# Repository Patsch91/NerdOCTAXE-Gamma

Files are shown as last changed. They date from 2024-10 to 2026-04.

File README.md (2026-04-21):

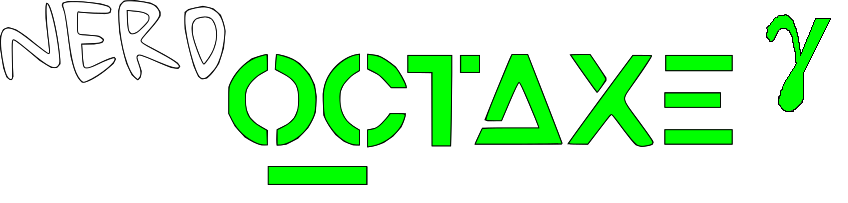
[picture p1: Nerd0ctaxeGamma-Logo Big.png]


**NerdOCTAXE-γ Rev3.4  **

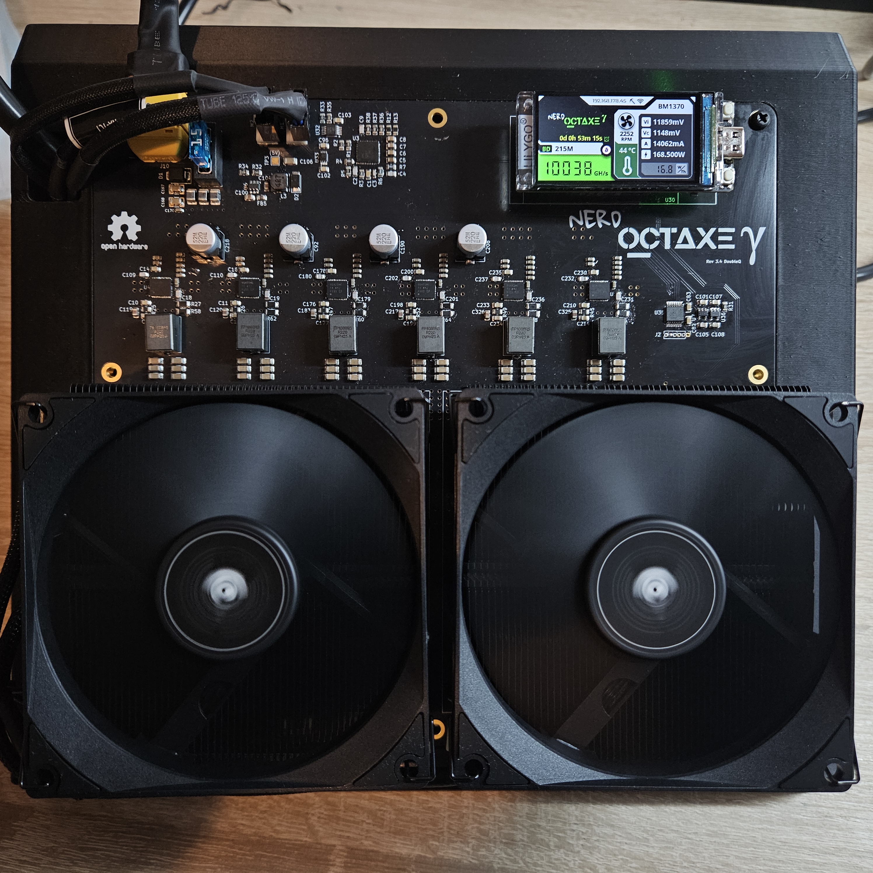
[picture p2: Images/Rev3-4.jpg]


Rev3.4:
- 6 Phase Buck Converter
- Added curcuit to read the internal temperature of each asic

The NerdOCTAXEγ runs with a modified version of the AxeOS: [ESP-Miner-NerdQAxe+](https://github.com/shufps/ESP-Miner-NerdQAxePlus) (Releases for NerdOCTAXE-Gamma)

To flash the Lilygo T-Display you can use the [Webflasher](https://shufps.github.io/nerdqaxe-web-flasher/)

-------------------------------

# Build

**DISCLAIMER:** This device is an *highly advanced* build and partly WIP. To get 8 Asics and the voltage regulator soldered properly *can* be very hard and frustrating if you are not used to soldering Asics or soldering in general. Using that amount of power, this device isn't a toy and you should know what you are doing - stay safe! Also this device is not intended or designed to run overclocked.

**PCB:** For example with the JLC Plugin for Kicad you can export the files out of Kicad to order directly from JLCPCB or any other PCB-Manufacturer. I tested my prototype with 1oz on inner and outer layers... working nice :) If anyone is testing 2/1oz or 2/2oz please let me know of the results you are seeing!

**BOM:** You can directly upload the .csv in this repo to Digikey. You will have to order the Lilygo T-Display S3 and the XT60PW-M seperately 

**HEATSINKS:** For this build I used two Thermalright AXP90-X53 

**ASICS:** This board utilizes Bitmains BM1370-Series. I tested boards with the following variants: BM1370BC < BM1370PA < BM1370PF 

Misc
====
If you like this project and want to support future work, feel free to donate to:
**`bc1q0ctaxeha3lpsaaz7kpjulflw2d9p66fhkp48dk`**

or related projects without which this project would not have been possible for me:

[Nerdaxe](https://github.com/BitMaker-hub/NerdAxeUltra)

[NerdQAxe+](https://github.com/shufps/qaxe)

[OSMU](https://osmu.wiki/)

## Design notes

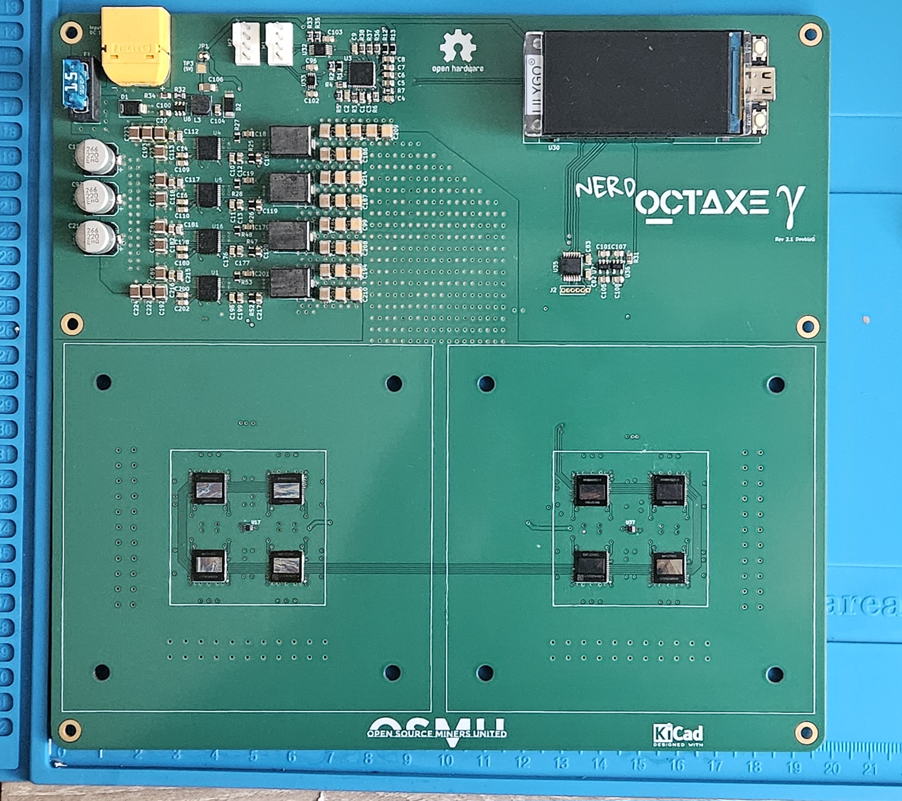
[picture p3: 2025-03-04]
Images/NerdOCTAXE-Gamma_DoubleQ PCB.jpg

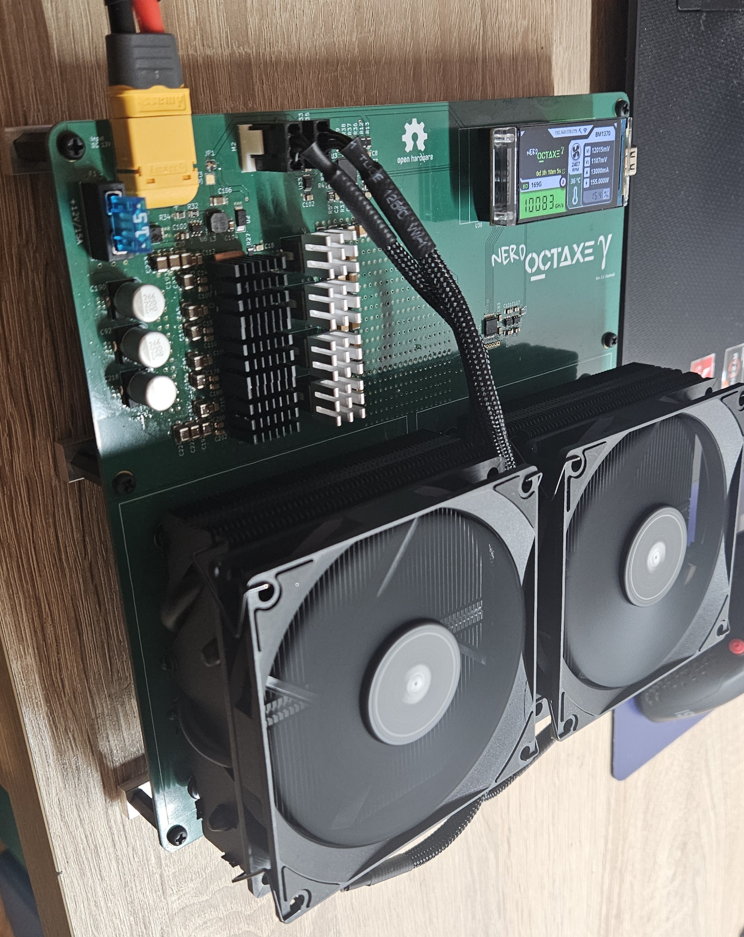
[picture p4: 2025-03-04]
Images/NerdOCTAXE-Gamma_DoubleQ (2).jpg

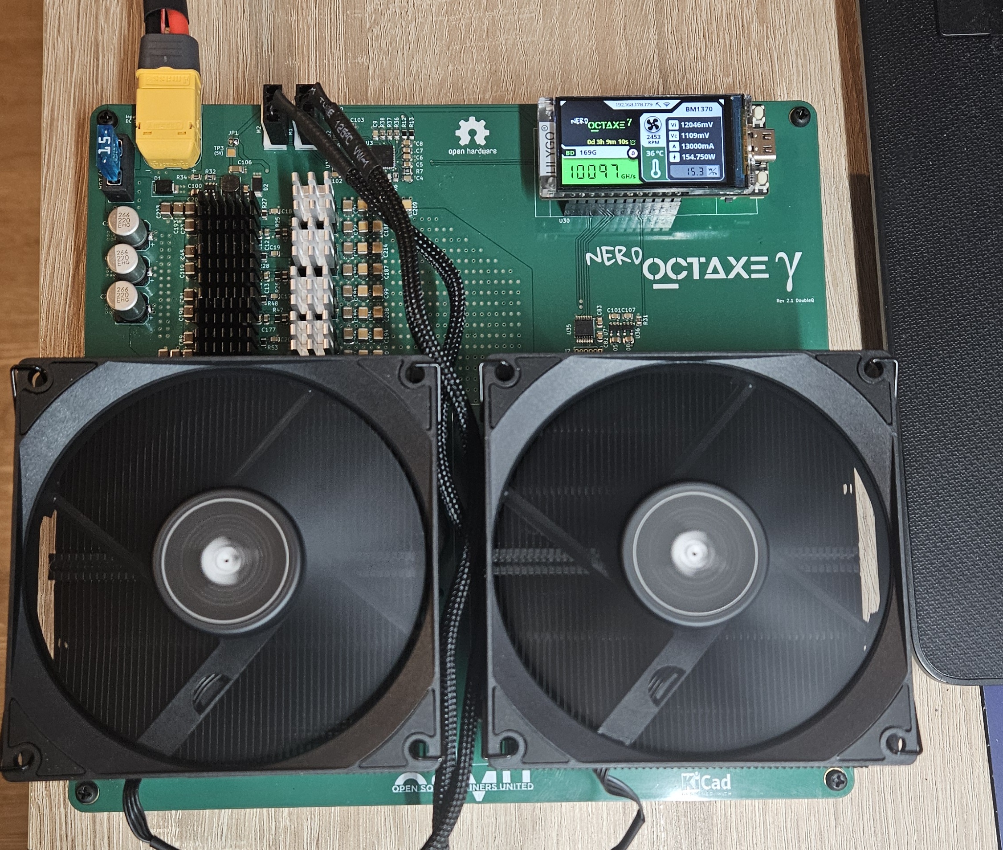
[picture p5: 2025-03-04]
Images/NerdOCTAXE-Gamma_DoubleQ.jpg

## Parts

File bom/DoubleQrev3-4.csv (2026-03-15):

Reference | Value | Footprint | Qty | Distributor | OrderNr
C1 | 2.2n | Capacitor_SMD:C_0805_2012Metric | 1 | D | 1276-2993-1-ND
C2,C4,C9,C109,C110,C180,C202,C212,C232,C237,C327 | 1n/0.7mm | Capacitor_SMD:C_0805_2012Metric | 11 | D | 490-6445-1-ND
C3 | 12p | Capacitor_SMD:C_0603_1608Metric | 1 | D | 478-KGM15ACG2A120JMCT-ND
C5 | 330n | Capacitor_SMD:C_0805_2012Metric | 1 | D | 399-C0805C334K3RECAUTOCT-ND
C6,C8,C15,C17,C26,C27,C28,C30,C33,C35,C36,C37,C38,C40,C41,C42,C43,C44,C46,C49,C52,C54,C55,C56,C57,C58,C59,C60,C61,C62,C63,C65,C68,C70,C71,C72,C73,C74,C75,C76,C77,C78,C79,C85,C105,C108,C121,C123,C124,C125,C126,C127,C128,C129,C130,C131,C132,C134,C137,C139,C140,C141,C142,C143,C144,C145,C146,C147,C148,C150,C153,C155,C156,C157,C158,C159,C160,C161,C162,C163,C164,C166,C169,C171,C172,C173,C174,C175,C195,C196,C197,C203,C204,C211,C219,C221,C225,C226,C227,C228 | 1µ/25V | Capacitor_SMD:C_0805_2012Metric | 100 | D | 1276-1066-1-ND
C7 | 4.7µ | Capacitor_SMD:C_0805_2012Metric | 1 | D | 1276-1244-1-ND
C10,C11,C14,C16,C25,C82,C83,C87,C88,C96,C101,C102,C103,C107,C176,C178,C198,C200,C210,C229,C230,C233,C235 | 100n/0.7mm | Capacitor_SMD:C_0805_2012Metric | 23 | D | 311-3037-1-ND
C12,C13,C177,C199,C214,C234 | 2.2µ | Capacitor_SMD:C_0805_2012Metric | 6 | D | 1276-6458-1-ND
C18,C19,C179,C201,C231,C236 | 6.8n | Capacitor_SMD:C_0805_2012Metric | 6 | D | 490-GRM2165C2A682JA01DCT-ND
C20,C23,C29,C34,C45,C47,C53,C64,C69,C80,C81,C89,C111,C112,C113,C117,C118,C122,C133,C135,C136,C138,C149,C151,C152,C154,C165,C170,C181,C182,C191,C192,C207,C209,C215,C216,C222,C296,C297,C298,C299,C300,C301,C302,C303,C304,C305,C306,C307,C308,C309,C310,C311,C312,C313,C314,C315,C316,C317,C318,C319,C320,C321,C322,C323,C324 | 10uF | Capacitor_SMD:C_0603_1608Metric | 66 | D | 1276-1870-1-ND
C21,C22,C24,C31,C32,C39,C48,C50,C51,C66,C67,C84,C86,C90,C91,C93,C94,C95,C97,C98,C99,C184,C185,C186,C187,C188,C189,C193,C194,C206,C223,C224,C238,C239,C240,C241,C242,C243,C244,C245,C246,C247,C248,C249,C250,C251,C252,C253,C254,C255,C256,C257,C258,C259,C260,C261,C262,C263,C264,C265,C266,C267,C268,C269,C270,C271,C272,C273,C274,C275,C276,C277,C278,C279,C280,C281,C282,C283,C284,C285,C286,C287,C288,C289,C290,C291,C292,C293,C294,C295,C480,C481 | 100µF | Capacitor_SMD:C_1206_3216Metric | 92 | D | 1276-1782-1-ND
C92,C190,C208,C218,C329 | 220µ/25V | Capacitor_SMD:CP_Elec_8x10 | 5 | D | 565-HHXE250ARA221MHA0GCT-ND
C100,C119,C120,C183,C217,C325,C326 | 10µ | Capacitor_SMD:C_0805_2012Metric | 7 | D | 445-5984-1-ND
C104 | 10n | Capacitor_SMD:C_0805_2012Metric | 1 | D | 445-6947-1-ND
C106 | 22µ/16V | Capacitor_SMD:C_1206_3216Metric | 1 | D | 1276-2728-1-ND
C114,C115,C116 | 22p | Capacitor_SMD:C_0603_1608Metric | 3 | D | 478-KGM15ACG1H220JTCT-ND
C167,C168 | 10µ | Capacitor_SMD:C_1210_3225Metric_Pad1.33x2.70mm_HandSolder | 2 | D | 1276-6767-1-ND
C205,C213,C220,C328 | 100nF | Capacitor_SMD:C_0805_2012Metric | 4 | D | 399-C0805C104K5RACTUCT-ND
D1 | SMBJ12A | Diode_SMD:D_SMB | 1 | D | SMBJ12ALFCT-ND
D2 | PMEG4030EP,115 | Diode_SMD:D_SOD-128 | 1 | D | 1727-5841-1-ND
D3 | 1N5819 | Diode_SMD:D_SOD-123 | 1 | D | 31-1N5819HWQ-7-FCT-ND
F1 | 3568 | 8Axe:Fuseholder Blade_3568 | 1 | D | 36-3568-ND
FB1,FB2,FB3,FB4,FB5 | BLM21PG221SN1D | Resistor_SMD:R_0805_2012Metric | 5 | D | 490-1054-1-ND
FB6,FB7,FB8 | BLE32SN120SN1L | Resistor_SMD:R_1210_3225Metric_Pad1.30x2.65mm_HandSolder | 3 | D | 490-BLE32SN120SN1LCT-ND
J5,J6 | Conn_01x12-Socket |  | 2 | D | 732-61301211821-ND
J7,J8 | Conn_01x12-Header |  | 2 | D | 2057-PH1-12-UA-ND
J10 | Connector 02x01 | Connector_AMASS:AMASS_XT60PW-M_1x02_P7.20mm_Horizontal | 1 | X
L1,L2,L4,L5,L6,L7 | 220nH | Nerd8:IFLR-4031GC-01-8x10 | 6 | D | 283-FP1008R5-R220-RCT-ND
L3 | 4.7µH/2.3A/2.7A | Inductor_SMD:L_Taiyo-Yuden_NR-50xx | 1 | D | 732-7244-1-ND
M1,M2 | Fan_4pin | Connector:FanPinHeader_1x04_P2.54mm_Vertical | 2 | D | WM4330-ND
R1 | 16.5k | Resistor_SMD:R_0805_2012Metric | 1 | D | 541-16.5KCCT-ND
R2 | 24.3k | Resistor_SMD:R_0805_2012Metric | 1 | D | 311-24.3KCRCT-ND
R3 | 24.9k | Resistor_SMD:R_0805_2012Metric | 1 | D | RMCF0805FT24K9CT-ND
R4 | 100k | Resistor_SMD:R_0805_2012Metric | 1 | D | RMCF0805FT100KCT-ND
R5 | 121k | Resistor_SMD:R_0805_2012Metric | 1 | D | RMCF0805FT121KCT-ND
R6 | 8.06k | Resistor_SMD:R_0805_2012Metric | 1 | D | RMCF0805FT8K06CT-ND
R7 | 2.55k | Resistor_SMD:R_0805_2012Metric | 1 | D | 311-2.55KCRCT-ND
R8,R10,R14,R16,R18,R20,R22,R24,R31,R36,R37,R38,R42,R57 | 10k | Resistor_SMD:R_0805_2012Metric | 14 | D | RMCF0805FT10K0CT-ND
R9,R11,R15,R17,R19,R21,R23,R41 | 1k | Resistor_SMD:R_0805_2012Metric | 8 | D | RNCP0805FTD1K00CT-ND
R12,R13 | 2.2R/0.5W | Resistor_SMD:R_0805_2012Metric | 2 | D | 541-10524-1-ND
R25,R26,R45,R47,R49,R52 | 1R/0.5W | Resistor_SMD:R_0805_2012Metric | 6 | D | 541-1.00TCT-ND
R27,R58,R59,R60,R61,R62,R63,R64,R65,R66,R67,R68 | 2R/1W | Resistor_SMD:R_1206_3216Metric | 12 | D | 541-10616-1-ND
R29,R30 | 0 | Resistor_SMD:R_0805_2012Metric | 2 | D | RMCF0805ZT0R00CT-ND
R32 | 84.5k | Resistor_SMD:R_0805_2012Metric | 1 | D | 311-84.5KCRCT-ND
R33,R35,R43,R44 | 2.7k | Resistor_SMD:R_0805_2012Metric | 4 | D | RMCF0805FT2K70CT-ND
R34 | 16.2k | Resistor_SMD:R_0805_2012Metric | 1 | D | RMCF0805FT16K2CT-ND
R39,R40,R51,R54,R55,R56 | 100 | Resistor_SMD:R_0805_2012Metric | 6 | D | 311-100CRCT-ND
U1,U4,U5,U16,U18,U19 | CSD95472Q5MC | Nerd8:CSD95472-SON-5x6 | 6 | D | 296-43950-1-ND
U2,U9,U10,U11,U12,U13,U14,U15 | BM1370_mode1 | Nerd8:BM1370 | 8 | X
U3 | TPS53667 | Package_DFN_QFN:Texas_RHA0040B_VQFN-40-1EP_6x6mm_P0.5mm_EP4.15x4.15mm_ThermalVias | 1 | D | 296-44940-1-ND
U6 | AP3211 | Package_TO_SOT_SMD:SOT-23-6 | 1 | D | AP3211KTR-G1DICT-ND
U7 | MCP1824T-0802E | Package_TO_SOT_SMD:SOT-23-5 | 1 | D | MCP1824T-0802E/OTCT-ND
U8 | 25MHz | Oscillator:Oscillator_SMD_EuroQuartz_XO32-4Pin_3.2x2.5mm | 1 | D | 1923-1664-1-ND
U17,U37,U38 | TMP1075 | Nerd8:TMP1075-DRL | 3 | D | 296-TMP1075NDRLRCT-ND
U20 | TMP451A | Package_SON:WSON-8-1EP_2x2mm_P0.5mm_EP0.9x1.6mm | 1 | D | 296-TMP451AQDQWRQ1CT-ND
U21,U23 | TMUX1109RSVR | Package_DFN_QFN:UQFN-16_1.8x2.6mm_P0.4mm | 2 | D | 296-53439-1-ND
U22 | TMP451J | Package_SON:WSON-8-1EP_2x2mm_P0.5mm_EP0.9x1.6mm | 1 | D | 296-TMP451JQDQWRQ1CT-ND
U30 | T-Display-S3 | myfootprints:T-Display-S3 | 1 | X
U32 | EMC2302-1 | Package_SO:MSOP-10_3x3mm_P0.5mm | 1 | D | EMC2302-1-AIZL-CT-ND
U33 | TXU0102-DCU | Package_SO:VSSOP-8_2.3x2mm_P0.5mm | 1 | D | 296-TXU0102DCURCT-ND
U35 | TXU0304PW | Package_SO:TSSOP-14-1EP_4.4x5mm_P0.65mm | 1 | D | 296-TXU0304PWRCT-ND
U36 | MCP1824T-1202E | Package_TO_SOT_SMD:SOT-23-5 | 1 | D | MCP1824T-1202E/OTCT-ND

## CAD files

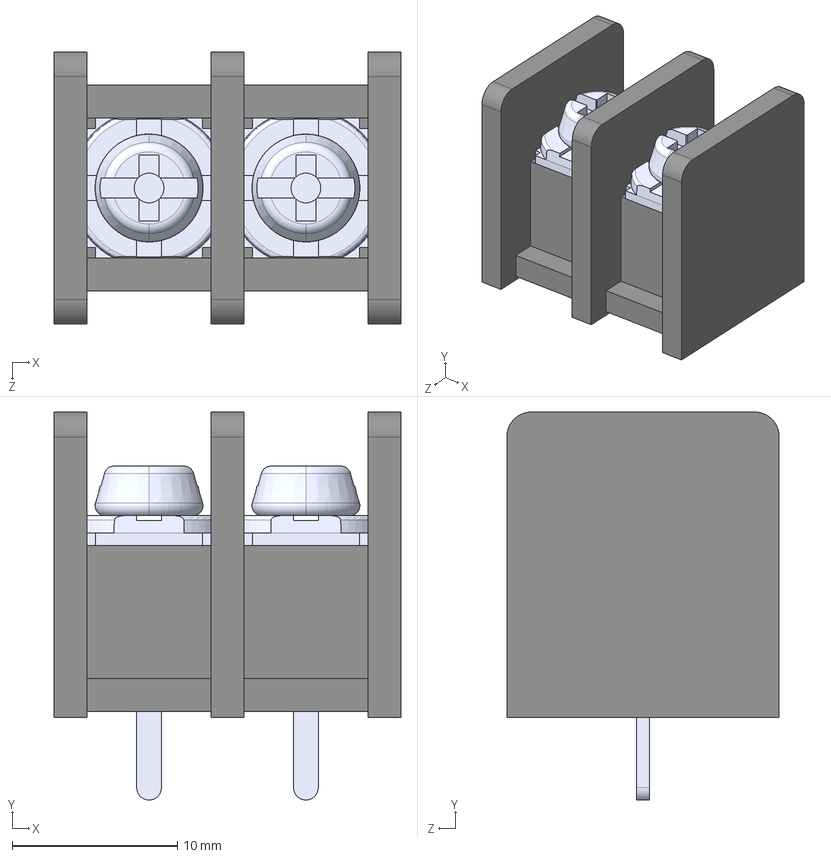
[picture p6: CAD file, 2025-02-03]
3d/OSTYK51102030.STEP
21.0 x 23.5 x 16.5 mm

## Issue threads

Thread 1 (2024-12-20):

Contact

minimalist15, 2024-12-20:
Hi,
first of all amazing stuff you're doing..
I wanted to try and build one as well but I am a bit confused as to what is your "final" set up for the moment in terms of BOM.
I saw you suggested to use different heatsinks and that you have moved to a 6 layer PCB.
I would like to try to do this as well, just curious as to what guidelines you'd give now as some time has passed since your last updates.
Wanted to reach out but couldn't find you anywhere.

Patsch91, 2024-12-27:
Hi,
I would recommend to use the "LED" branch with at least 1/1oz on the PCB. This PCB is running for weeks now without any major problems :)
In the LED-branch you will find the heatsinks I recommend to use... I did ot find any better alteratives regarding price and size as the space is limited by the case :)
If you have anyy specific questions, just let me know!

Closed 2025-03-30.

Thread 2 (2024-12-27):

cooler compatibility

DerpMcGeee, 2024-12-27:
can you change the holes into slots to be compatible with am4 coolers? 90x54 compared to the 94x56

DerpMcGeee, 2024-12-27:
too small to cover asics ignore me

ixtech-designs, 2025-03-28:
the LGA_Design branch has footprint to match the LGA115X coolers

Closed 2025-03-30.

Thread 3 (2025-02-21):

Guide

AlvaTM, 2025-02-21:
I'm really intrested in this project but I have the worst time understanding github and how things are in steps on here. Do you by chance have a the guide on another site? If not I understand. But this project is really cool!

Patsch91, 2025-04-02:
Hi, where excactly do you need some guidance?  In general terms you can open up the Boardfile with KiCad and download for example the Fabrication-Toolkit Plugin. This will export you the gerber files. You can upload these to a PCB manufacturer and let produce it. The parts needed you can find inn the "BOM"-folder.  With the PCB and the Parts at your hand you can open up the "ibom.html" and start soldering it all together :)  I wouldn´t recommend to start with this project without some (many) hours of soldering experience! Probably would get frustrating very fast :)

luiskellermann, 2025-05-07:
Hi Patsch91, i also wanna solder your project myself. Could you contact me on telegram for a quick guidance on how to order on JLCPCB. I just wanna make sure that I clicked the right boxes on KICAD for the export of the Gerber files and for the purchasing on JLCPCB. Would be very kind if you can dm me on telegram. Telegram Username: @luiskellermann

luiskellermann, 2025-05-07:
And can you clarify which of the 3 BOM's is the right one. I wanna order the best working built you currently have. Thank you so much.

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

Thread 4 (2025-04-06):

Regulator very hot, probably assembly defect...

earlynerd, 2025-04-06:
Hi, I built a small run of your octaxe lga design! First I want to say thanks for publishing such a professional hardware design, having it fabricated and purchasing components was easy. I am fairly experienced in smt assembly, and have stuffed the boards by hand with a solder stencil.

It looks great, it boots up, the log says that it finds all 8 Asics, it ramps up their clocks and connects to my pool, and then... The regulator chips get screaming hot, over 100C, over a few seconds and the power cycles on and off. Alternating between like 225W and 0W.  It never reports any hashes.

I expect I've probably made an error in assembly for these boards. This is the first miner I've ever built. Or used actually. I measure like 1.9 Ohms across the Asic power pads of the bare chips. My first thought was a short circuit on the 1V rail but I can't seem to find it.

I wanted to ask if you had any thoughts about what my issue might be. I've pulled the Asics off of it and the short circuit is gone, but maybe the low resistance I was measuring is normal?

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

Patsch91, 2025-04-06:
Hey there! First you definately want to put any kind of heatsinks on the 4 Mosfets to get them cooler. I can´t run the Octaxe without heatsinks on the 4xCSDs - thats why I am constantly trying to improve the Buck Section for better cooling options at the moment :)

The low resistance between the big asic pads is normal.
My guess would be that the Buck went to overtemperature fault mode and shut off. So first I would try to put the best kind of heatsink option you could find and place them over the CSDs and try again. For first startups I recommend a Labbench PSU (capable of at least 15Amps at 12V) where you can observe the power drawn of the Miner to double check if the power values are correct in the OS. Another thing is to triple check if the heatsinks are mounted correctly (not bending the pcb but firm enough to make good contact - thats a veeeeeery thin line to walk on)

I once had an issue with alternating Wattage displayed on the OS ... After searching a lot it came out the TPS was a faulty one :/

Sooo in short words:
First check proper heatsink mounting and try to cool the 4xCSDs on the PCB in the best way you can do and try again with a PSU where you can check the power drawn of the PCB.
If the PSU shows consistently about 12-15Amps without jumping around - but the OS Wattage display is jumping around then probably check your tps!

Hope this helps!

earlynerd, 2025-04-06:
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

Thanks for the quick reply, I will try your suggestions! Thank you. These things getting scary hot

earlynerd, 2025-04-16:
So I have done some further investigating, stuffed several more boards, and still not really sure what's going on with my board.  I wanted to ask if you might share some kinda normal looking numbers for Pin, Pout, Iout, and temperature as reported from the TPS on one of your boaeds? Mine are quite bad, and I am still hunting for the reason why. Even dropping the voltage and Asic frequency very low using the config and sticking a heatsink on I can't get it to run for more than a minute. Efficiency according to Pout/Pin is around 50% and I know that this type of regulator commonly is above 90%. I have a bench supply at work that can provide 20A and the number it reported seemed to match what was shown on the display.

I added some code to dump the TPS registers and did not find anything more interesting than the fact that it increases in temperature until it hits 125C and then shuts off.  The config it is reporting at runtime matches what it's being initialized with.  It isn't reporting any other faults. On boards without Asics installed it runs fine, but theres no load in that case...

Patsch91, 2025-04-16:
Ok that sounds a bit weird ... could you send me a picture of the heatsinks you are using on the CSDs?
What is the layer thickness of your PCB?
How many Watts is your UI and the PSU showing until it shuts off?

earlynerd, 2025-04-16:
I sliced a few fins off a larger heatsink. I've been looking for one that fits the mounting pattern on your board without a lot of luck, I may machine something better. I've also been sticking a heatsink to the bottom under the regulator since the csds will reject a lot of their heat into the board itself. I can't keep them from overheating even when pointing an electric duster at the heatsink.

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

I also added a dummy load to a different board that is fully populated except for the Asics. A few feet of 18awg wire. The logs say that it consumed 47W from the 12V supply to put 25W into the load.

I ordered the pcbs from JLC and selected 1oz outer and 1oz inner copper, so there's 6oz total thickness there.

Here's a Serial log output of it booting up and then overheating. It doesn't actually get all the way through the frequency ramp up.

[nerdaxe boot apr11.txt](https://github.com/user-attachments/files/19772275/nerdaxe.boot.apr11.txt)

Here's a thermal cam video of turning it on. Heatsink removed here.
https://github.com/user-attachments/assets/bd13d03d-15d8-473a-95d1-1bd69ccb79b8

Probably next I will poke around with the oscilloscope.

Patsch91, 2025-04-20:
Oh well this definately isnt looking good! So there probably is a solder issue :/

I have a 1/1oz Board too, so this wont be the problem ... I only can think of a soldering issue on the CSDs.

Ah well and I see on the Picture you send (Backside with the heatsink) it looks like somethin is wrong with your C116!

earlynerd, 2025-04-20:
I just discovered that damaged capacitor (and pad) and the resistor next to it was damaged also, good eye spotting that in the photo.

I've now got two more units that are hashing on one Asic each successfully. I think the issue was indeed mostly solder related. I do still measure lower than ideal efficiency on the boards which are hashing, but it may be due to the load being too light with only one asic. And I also measure that the displayed input current is not correct, off by almost 20%.  so any efficiency calculated based on that will not be useful anyway.

I think that the chip doesn't really have a direct measurement of input current and I guess it must calculate it from the phase current and the duty cycle. There's a register for calibrating the output current measurement offset which may improve the accuracy of the measurements it is making.

I will close this issue, thanks for your help.

Closed 2025-04-20.

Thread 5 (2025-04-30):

I2c pullups absent

earlynerd, 2025-04-30:
Doesn't appear that the i2c bus has any pullup resistors on SDA or SCL.  Internal pullups are not strong enough for i2c comms at 400khz (or even 100khz). The internal ones are ~45-50k but 400khz i2c requires 2.2k or so on both SDA and SCL.

Patsch91, 2025-04-30:
The displaymodule has internal pullups on GPIO43 and 44. I actually cann´t find any specific values but never had any problems on any board so far(Qaxe/Haxe/Octaxe etc)... Is there something not working on your board?

earlynerd, 2025-04-30:
There are no pullups on the display board. It somehow is working with only the internal pullups, but that can't be working very well or completely consistently. i can collect a scope shot to see if it is an issue, but you may consider adding the pullups to the latest revision anyway.

https://github.com/Xinyuan-LilyGO/T-Display-S3/blob/main/schematic/T_Display_S3.pdf

Patsch91, 2025-04-30:
Oh a scope shot would be very interesting then! Would love to see that!

earlynerd, 2025-04-30:
You can find the value of the internal pullups on the esp32-s3 datasheet page 29,
They are 45k. https://www.espressif.com/sites/default/files/documentation/esp32-s3-wroom-1_wroom-1u_datasheet_en.pdf

earlynerd, 2025-04-30:
Heres the scope shot. you can see how the clock signal never is able to return to high level while the transfer is happening. this is due to there not being stronger pullups to supply the current required to charge the bus capacitance. On the data line, it takes multiple bit periods before it returns to 90% of the supply voltage. Its impressive it still works, but its working in spite of the lack of pullups, and you should add the appropriate pullups for the speed of the bus to help make sure it always works.  I can Share the capture file if youd like to look closer. It can be opened in Saleae logic.

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

earlynerd, 2025-04-30:
I have fixed it already on my board, I undid the fix to capture this shot. I will put the pullups back and capture again for comparison

earlynerd, 2025-04-30:
This is with 2.2k pullup on SDA and SCL. 2.2k is not always the right value, it depends on the bitrate configured. It looks like it's being set up for 400khz in the firmware and 2.2k is a good value at 3.3V and that bitrate for most implementations.

Patsch91, 2025-04-30:
2,7k would already be in the Bom and would require additional part ... maybe that 2.7k would work good enough? :)

earlynerd, 2025-05-02:
Also I finally found the problem with the boards I built, I stuffed the regulator bootstrap caps with 1nF instead of 100nF 😬

Patsch91, 2025-05-05:
Added 2.7k resistors on SCL/SDA

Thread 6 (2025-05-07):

Question about ordering

luiskellermann, 2025-05-07:
Hi Patsch91, i also wanna solder your project myself. Could you contact me on telegram for a quick guidance on how to order on JLCPCB. I just wanna make sure that I clicked the right boxes on KICAD for the export of the Gerber files and for the purchasing on JLCPCB. Would be very kind if you can dm me on telegram. Telegram Username: @luiskellermann

luiskellermann, 2025-05-07:
And can you clarify which of the 3 BOM's is the right one. I wanna order the best working built you currently have. Thank you so much.

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

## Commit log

2024-08-20 Added 4th Phase Buck
    Started to add 4th Phase for the Buck, implementing BM1370 footprint etc
    [BM1368-1.kicad_sch, BM1368-2.kicad_sch, BM1368-3.kicad_sch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]
2024-08-25 Phase4 Disable
    Phase4-Disable Jumper
    [power.kicad_sch]
2024-08-25 Changed LDO to 1V2 and original 1V2 to VDD
    1V8 LDO replaced with 1V2 LDO
    Crystal replaced
    [BM1368-1.kicad_sch, BM1368-2.kicad_sch, BM1368-3.kicad_sch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]
2024-09-04 silkscreen changes
    heatsink area
2024-09-09 minor chages
    R3 to 49.9K
    added DK-Bom
    [bom.csv, designators.csv, octaxe-gamma.csv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]
2024-09-15 Changed to 6L PCB
2024-09-15 JLC
    JLC Zip File
    [bom.csv]
2024-10-27 Fuse from 12A to 15A
    [Nerd8.kicad_sch]
2024-10-29 changed imon to 33,2k for 180Amps
    [power.kicad_sch]
2024-10-29 update bom with 33.2k
    [octaxe-gamma_DigiKey.csv]
2024-11-03 Update README.md
    Case BOM
2024-11-03 Added 3D Files
    Backplate 3D Files
    [Backplate Octaxe.3mf, Backplate Octaxe.f3d, Backplate Octaxe.stl]
2024-11-07 LED Connector
    [Nerd8.kicad_pcb, pi.kicad_sch]
2024-11-07 100nF for TXU0101
    [Nerd8.kicad_pcb, pi.kicad_sch]
2024-11-07 Test bottomside open mask
    [Nerd8.kicad_pcb]
2024-11-10 layer switches
    [Nerd8.kicad_pcb]
2024-11-15 Input Cap 12V LED
    [Nerd8.kicad_pcb, Nerd8.kicad_sch, pi.kicad_sch]
2024-11-15 BOM changes
    1nF to 1nF 0.7mm etc
    [BM1368-1.kicad_sch, BM1368-2.kicad_sch, BM1368-3.kicad_sch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]
2024-11-15 BOM partdescriptions
    [BM1368-1.kicad_sch, BM1368-2.kicad_sch, BM1368-3.kicad_sch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]
2024-11-15 minor changes
    [Nerd8.kicad_pcb, bom.csv, designators.csv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]
2024-12-22 Added Backplate designs
    [Backplate logo with switch.3mf, Backplate logo with switch.stl, Backplate with logo.3mf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]
2025-02-06 GND Vias
    [Nerd8.kicad_pcb]
2025-02-07 XT60 test
    [Nerd8.kicad_pcb]
2025-02-07 12V Vias
    [Nerd8.kicad_pcb]
2025-03-04 mounting holes
    [Nerd8.kicad_pcb]
2025-03-14 Mountingholes CSD
    [Nerd8.kicad_pcb]
2025-03-15 0.16mm spacing
    [Nerd8.kicad_pcb]
2025-03-23 Buck rotation test
    Different Buck Layout
    [Nerd8.kicad_pcb, pi.kicad_sch, power.kicad_sch]
2025-05-05 added i2c pullups
    [Nerd8.kicad_pcb, pi.kicad_sch]
2025-05-05 Added pullups to bom and ibom
    [NerdOctaxe-Gamma DoubleQ_Digi.csv]
2025-09-30 board rev 3.0
    - 6 phases using TPS53667
    - Changed current MLCC capacitors to reduce BOM parts and rds on VRs
    - Beads at LDOs, TDisplay, fans and Power input (EMC)
    - Changed routing to allow better VDD circuit on bottom
    - Reduced VDD area to avoid EMI
    - New Layer distribution to reduce EMI
    [Asic0.kicad_sch, Nerd8.kicad_pcb, Nerd8.kicad_sch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]
2025-09-30 ibom update + bitronics logo
    [Nerd8.kicad_pcb]
2025-09-30 add gerbers + production files
    [CPL_file.csv, Nerd8-B_Cu.gbl, Nerd8-B_Mask.gbs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]
2025-10-14 Refactored buck stage and improved EMI performance
    I've made several changes that I’d like to explain. Not sure yet if all of them are optimal, but they reflect my impressions and should help in several areas.
    - Increased buck converter from 4 to 6 phases (now using TPS53667 controller).
    - Changed layer stack to keep GND between VDD planes (to improve EMI).
    - Added EMI filters at input, power beads, and additional ferrite beads in the 3V3 and 5V sections.
    - Relocated the 5V LDO to optimize space in the regulator area.
    - Standardized some input capacitors in the buck regulator stage.
    [Asic0.kicad_sch, DoubleQrev3.csv, Nerd8.kicad_sch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]
2025-11-17 Added TMP451 to schematic
    [Asic0.kicad_sch, bm1366.kicad_sch, pi.kicad_sch]
2025-11-17 PCB w Tempmeasurement
    [Nerd8.kicad_pcb, Nerd8.kicad_sch, bm1366.kicad_sch]
2025-12-16 changed GPIOs
    [Nerd8.kicad_pcb, pi.kicad_sch]
2026-01-26 Corrected Partnumbers (DK)
    [Asic0.kicad_sch, Nerd8.kicad_pcb, Nerd8.kicad_sch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]
2026-01-29 Board Rev + Bom
    Changes to R-C Values Snubber
    BOM / iBOM / Partnumbers
    [DoubleQ.csv, DoubleQrev3-4.csv, DoubleQrev3-4_DigiKey.csv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]
2026-02-04 Tmux Variant
    - Added curcuit to read internal Asictemps per chip
    - (i)BOM changes
    [Asic0.kicad_sch, DoubleQrev3-4.csv, DoubleQrev3-4_DigiKey.csv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]
2026-02-04 minor monk stuff
    [DoubleQrev3-4.csv, Nerd8.kicad_pcb, power.kicad_sch]
2026-02-08 BOM changes R3
    changed 33.2k to 24.9k
    [DoubleQrev3-4.csv, DoubleQrev3-4_DigiKey.csv, Nerd8.kicad_pcb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]
2026-03-15 BOM correction
    [DoubleQrev3-4.csv, Rev3-4 Digikey.csv, power.kicad_sch]
2026-04-26 TMP451 Footprint
    Fixed footprint of TMP451
    [Asic0.kicad_sch, Nerd8.kicad_pcb, Nerd8.kicad_sch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]
